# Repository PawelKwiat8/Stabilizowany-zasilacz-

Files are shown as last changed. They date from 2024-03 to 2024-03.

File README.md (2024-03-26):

# Stabilizowany zasilacz - Eagle Autodesk

## Opis projektu
Celem projektu jest zaprojektowanie  i wytworzenie płytki obwodu
drukowanego dla regulowanego stabilizowanego zasilacza laboratoryjnego, a nastepnie pzylutowanie odpowiednich komponentów.

## Schemat elektryczny
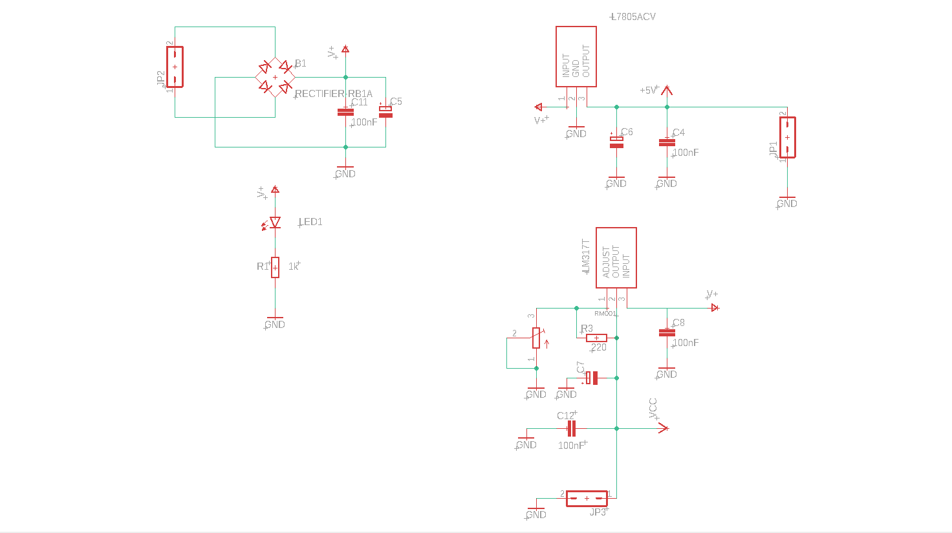
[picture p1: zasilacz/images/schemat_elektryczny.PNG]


## Rozmieszczenie elementów i ścieżek
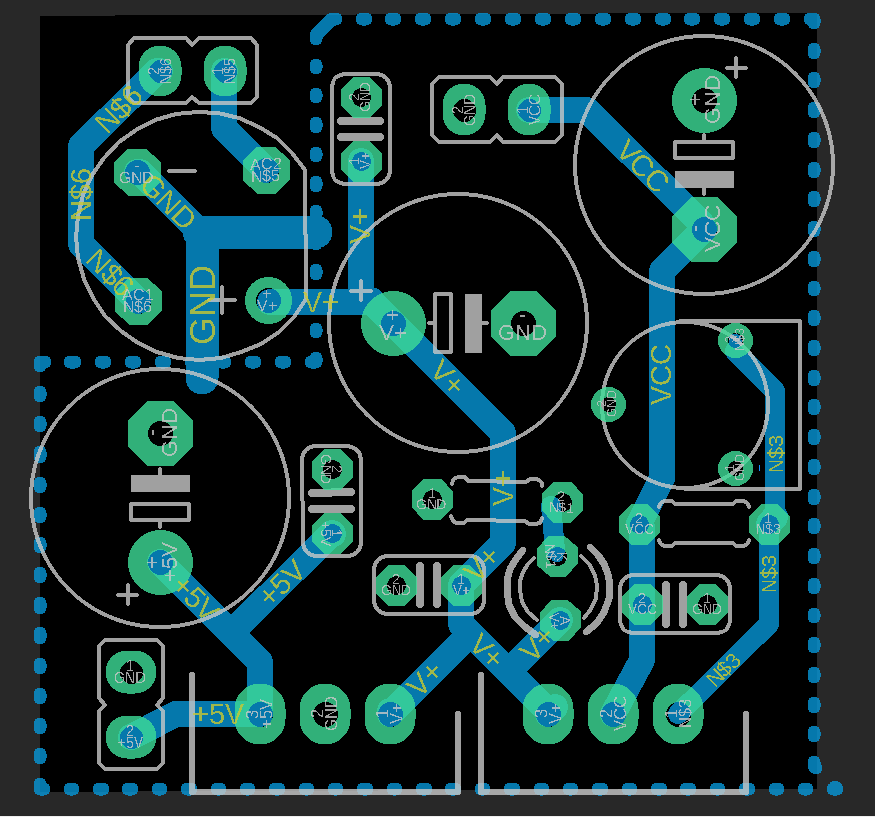
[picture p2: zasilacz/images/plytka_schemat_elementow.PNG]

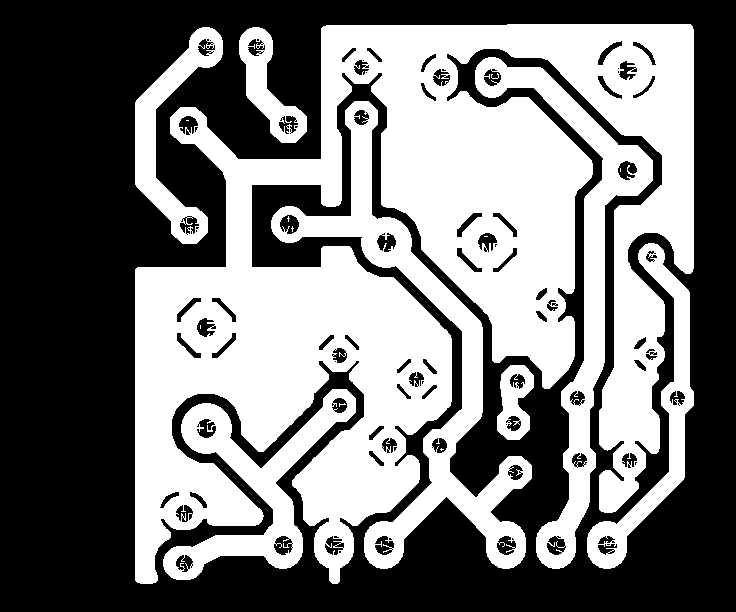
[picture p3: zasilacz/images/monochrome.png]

## Wykonany zasilacz , rozmiar 30x30mm
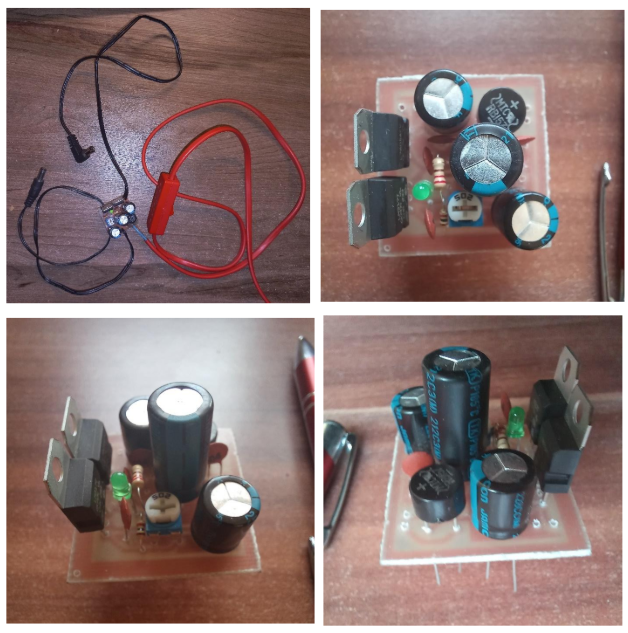
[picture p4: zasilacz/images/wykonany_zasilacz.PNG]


## Wykaz Elementów

| Symbol | Nazwa, oznaczenie | Ilość |
|---|---|---|
| C1, C2, C3, C4 | Kondensator, 100nF, 50V | 4 |
| C6, C7 | Kondensator, Jamicon, 470uF, 25V | 2 |
| C5 | Kondensator, Jamicon, 1000uF, 25V | 1 |
| R1 | Rezystor, R1/4W5%220R | 1 |
| R2 | Rezystor, R1/4W5%1k | 1 |
| R3 | Potencjometr, RM065 RM-P2, 5x5-502 | 1 |
| IC1 | Stabilizator, ST Microelectronics L7805ACV | 1  |
| IC2 | Stabilizator, ST Microelectronics LM317TT | 1  |
| LED1 | Dioda LED, Yetda Q300HCG1G | 1 |
| B1 | Mostek prostowniczy, RB157 | 1 |

## Wymagania dotyczące tego obwodu są następujące:
1. Sygnalizacja działania układu: Obwód powinien być wyposażony w diodę
sygnalizacyjną, która wskazuje, czy układ jest włączony i działa
poprawnie.
2. Małe wymiary zewnętrzne: Płytkę obwodu należy zaprojektować tak, aby
jej wymiary były możliwie jak najmniejsze oraz nie utrudniały ręcznego
montażu elementów.
3. Stabilizatory z możliwością montażu radiatora: Stabilizatory zostaną
umieszczone w taki sposób, aby można było dołączyć dodatkowy radiator
w celu efektywnego odprowadzenia ciepła.
4. Brak transformatora: Zasilanie zewnętrzne będzie dostarczane prądem
przemiennym o napięciu do 12V.
5. Zastosowanie rozlanej masy: W projekcie należy uwzględnić
zastosowanie rozlanej masy w celu zwiększenia stabilności i
odprowadzenia ciepła.
6. Układ filtrujący: Zasilacz będzie wyposażony w odpowiedni układ
filtrujący, który pozwoli na uzyskanie czystego napięcia wyjściowego.
7. Jednostronnie wykonana płytką: Płytka obwodu będzie wykonana
metodą grawerowania i trawienia, przy czym będzie to jednostronnie
wykonana płytką drukowaną.
8. Regulowane napięcie wyjściowe: Napięcie wyjściowe będzie można
regulować przy użyciu potencjometru, w zakresie od 2,5V do 12V.
Zadanie polega na zaprojektowaniu i wytworzeniu płytki obwodu
drukowanego, która spełni powyższe wymagania

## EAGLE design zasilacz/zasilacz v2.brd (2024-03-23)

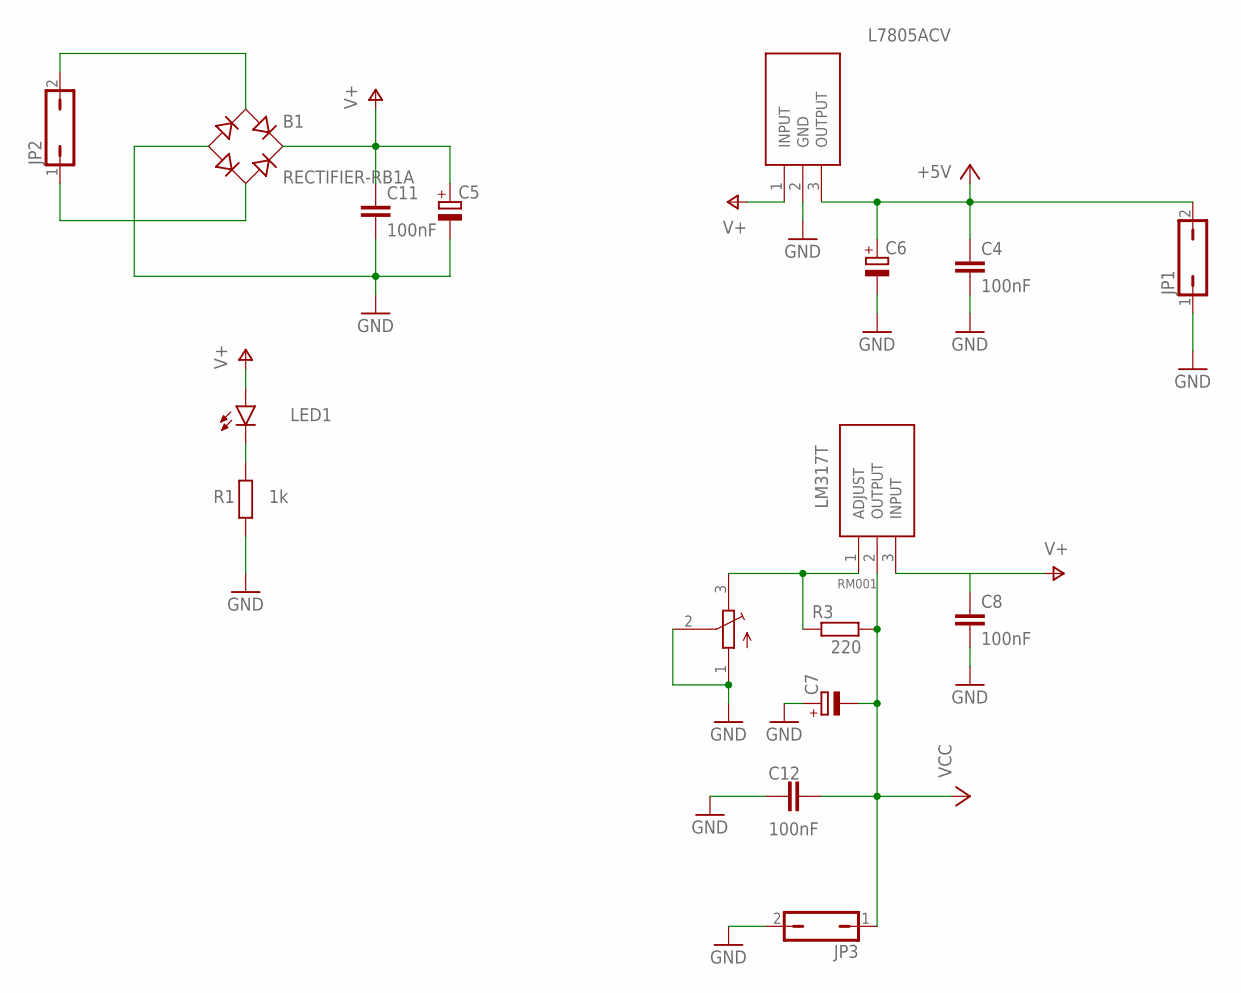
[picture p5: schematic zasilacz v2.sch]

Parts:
,1: LM317T; TO255P460X1020X2008-3P
B1: RECTIFIER-RB1A; RB1A
C4, C8, C11, C12: 100nF; C025-024X044
C5, C6, C7: CPOL-EUE5-10.5; E5-10,5
IC1: L7805ACV; TO255P460X1020X2008-3P
JP1, JP2, JP3: JP1Q; JP1
LED1: TLLG4400; LED3MM
R1: 1k; 0204/5
R3: 220; 0204/5
RM001: RM065

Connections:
+5V: C4.1, C6.+, IC1.3 (OUTPUT), JP1.2
GND: B1.-, C4.2, C5.-, C6.-, C7.+, C8.2, C11.2, C12.1, IC1.2 (GND), JP1.1, JP3.2, R1.1, RM001.1, RM001.2
unnamed: LED1.K (C), R1.2
unnamed: ,1.1 (ADJUST), R3.1, RM001.3
unnamed: B1.AC2, JP2.1
unnamed: B1.AC1, JP2.2
V+: ,1.3 (INPUT), B1.+, C5.+, C8.1, C11.1, IC1.1 (INPUT), LED1.A
VCC: ,1.2 (OUTPUT), C7.-, C12.2, JP3.1, R3.2

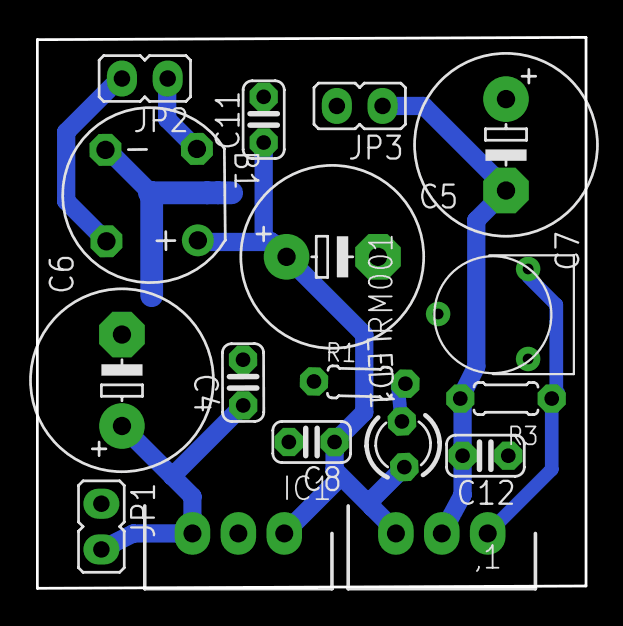
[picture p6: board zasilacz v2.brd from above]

Board: 2 copper layers, 30.5 x 30.6 mm, 17 parts (0 on the bottom side), 8 nets.
